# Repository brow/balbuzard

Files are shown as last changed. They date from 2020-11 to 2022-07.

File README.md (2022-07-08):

# Balbuzard

Balbuzard is a compact, ergonomic keyboard with 34–38 keys.

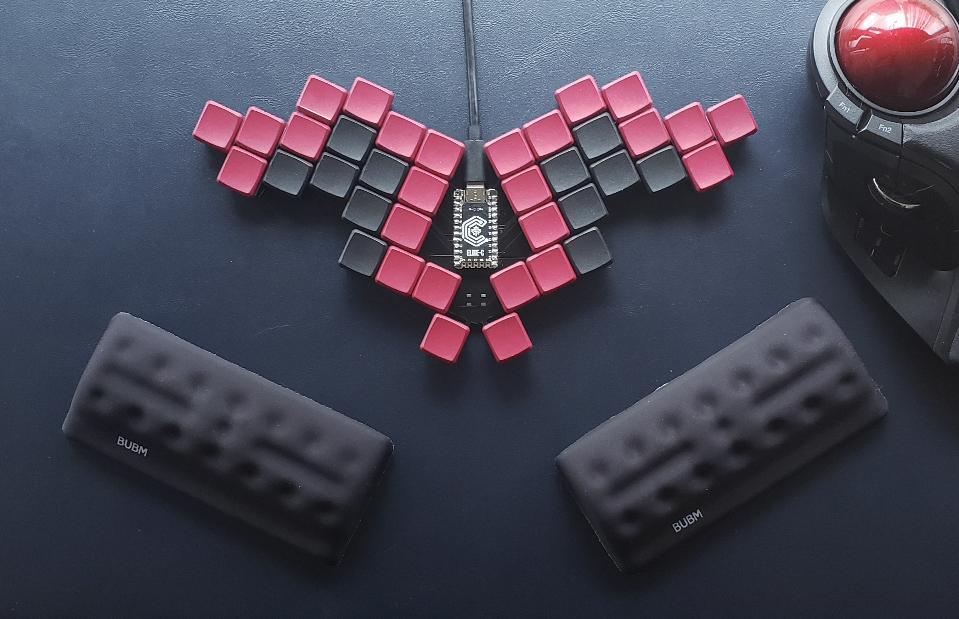
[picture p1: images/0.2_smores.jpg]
assembled Balbuzard 0.2


_Balbuzard 0.2 by [@smores56](https://github.com/smores56)_

## How do you type on that?
I've used Balbuzard as my main keyboard since 2019. My keymap looks like this:

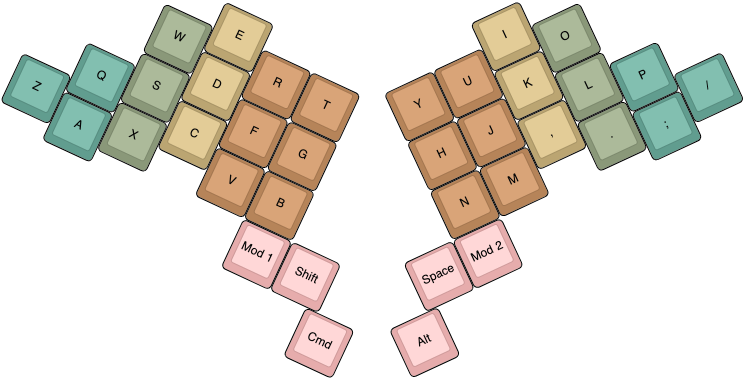
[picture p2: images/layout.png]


_Mod 1_ and _Mod 2_ activate alternate layers of the keymap, which contain symbols, arrows, backspace, etc.

## Versions

### [0.2: Low-profile](https://github.com/brow/balbuzard/releases/tag/v0.2)

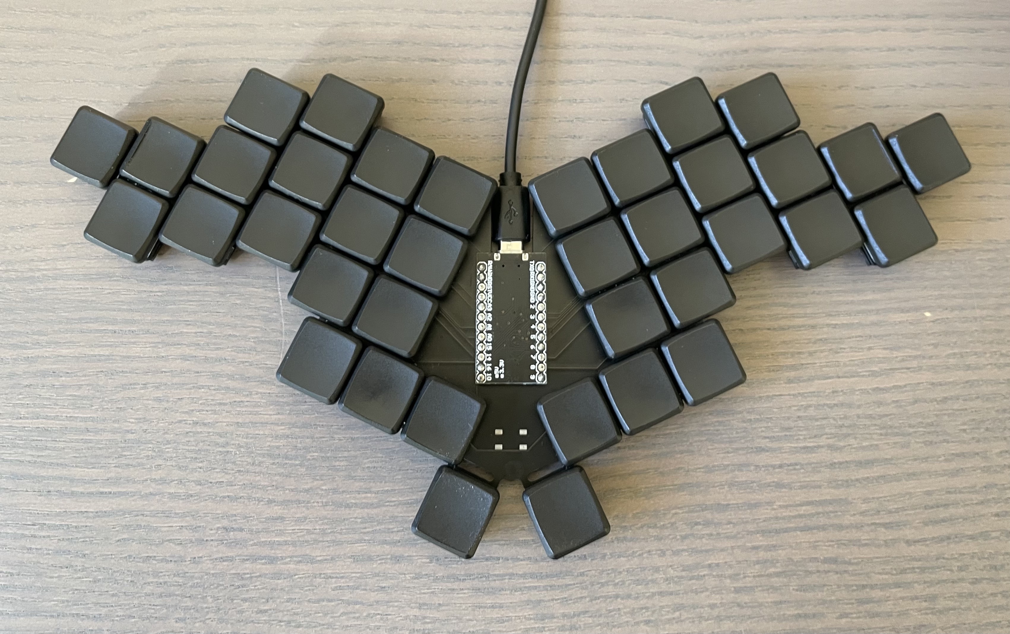
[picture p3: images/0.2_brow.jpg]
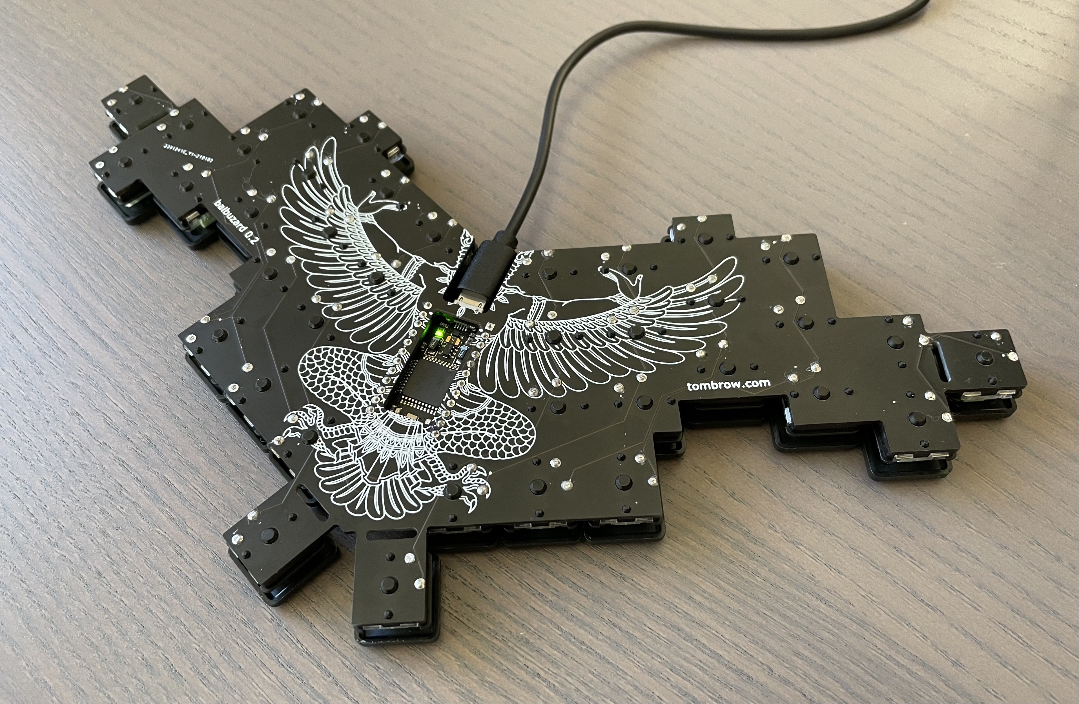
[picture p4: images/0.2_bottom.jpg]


- 34–38 keys
- Compatible with Choc (low-profile) switches
- SMD diodes concealed within switches
- Silkscreen on bottom
- Tighter key spacing
- Viewing window under microcontroller
- Adjustments to positions of columns and thumb keys
- **Firmware:** [brow/qmk_firmware@balbuzard-0.2](https://github.com/brow/qmk_firmware/tree/balbuzard-0.2)

### [0.1: Classic](https://github.com/brow/balbuzard/releases/tag/v0.1)

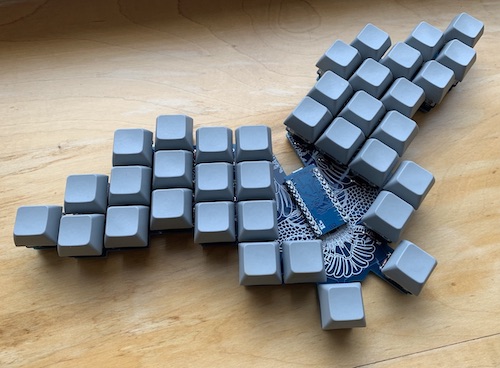
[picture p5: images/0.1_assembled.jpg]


- 36 keys
- Compatible with MX, Alps, and Choc (low-profile) switches
- Through-hole diodes nestled between switches
- Silkscreen on top
- **Firmware:** [brow/qmk_firmware@balbuzard-0.1](https://github.com/brow/qmk_firmware/tree/balbuzard-0.1)

## Using this repository

This repo contains the [Ergogen](https://github.com/mrzealot/ergogen) configuration that generates the KiCad PCB file.

Assuming you have [npm installed](https://www.npmjs.com/get-npm):

``` sh
git clone --recursive git@github.com:brow/balbuzard.git
cd balbuzard
make
```

Find the generated PCB at `output/pcbs/main.kicad_pcb`.

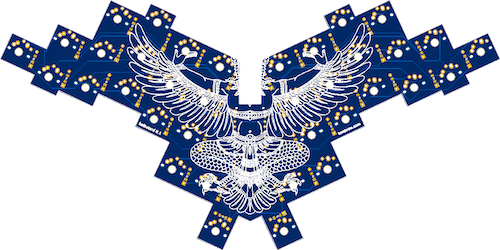
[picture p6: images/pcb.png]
pcb thumbnail image


## More photos

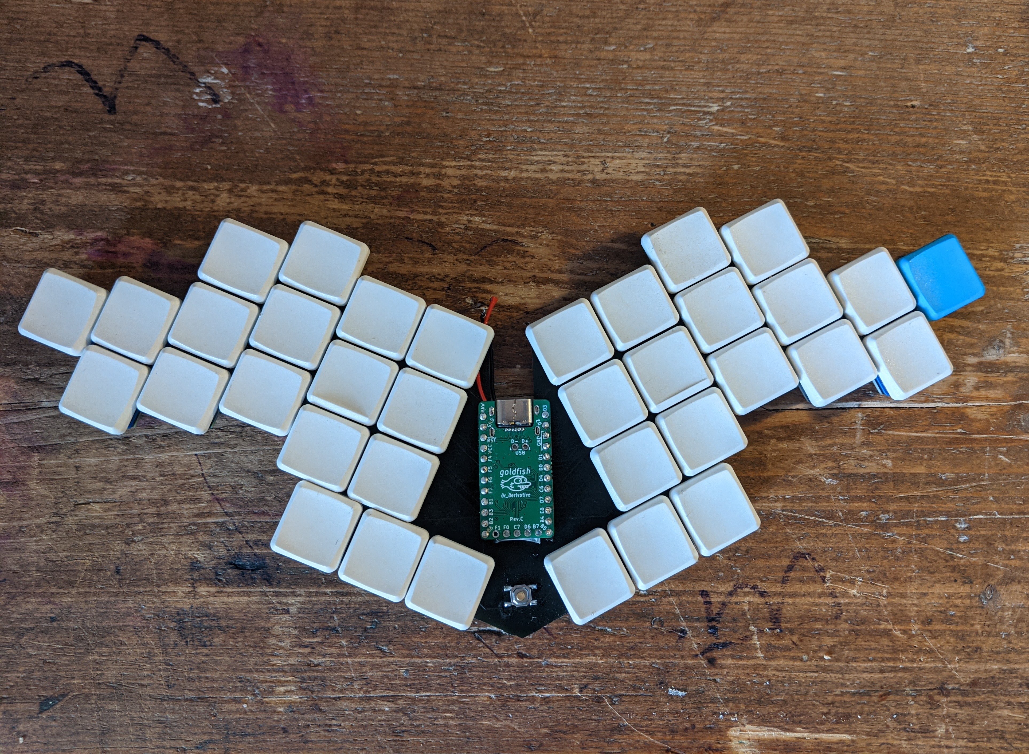
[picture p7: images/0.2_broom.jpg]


_Balbuzard 0.2 with optional thumbs removed, by [@davidphilipbarr](https://github.com/davidphilipbarr)_

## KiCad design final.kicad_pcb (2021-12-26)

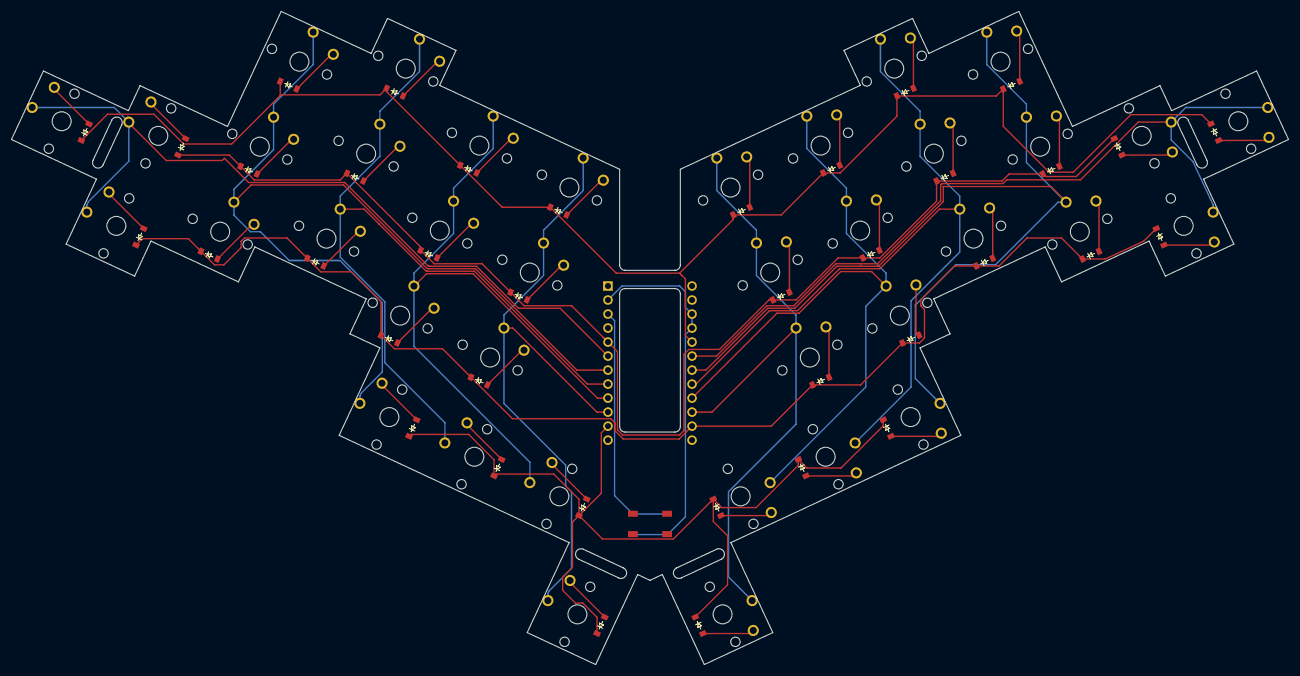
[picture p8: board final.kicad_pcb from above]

Board: 2 copper layers, 231.5 x 118.4 mm, 77 parts (0 on the bottom side), 52 nets.

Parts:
B1: SW_TACT_ALPS_SKQGABE010
D1, D2, D3, D4, D5, D6, D7, D8, D9, D10, D11, D12, D13, D14, D15, D16, D17, D18, D19, D20, D21, D22, D23, D24, D25, D26, D27, D28, D29, D30, D31, D32, D33, D34, D35, D36, D37, D38: ComboDiode
S1, S2, S3, S4, S5, S6, S7, S8, S9, S10, S11, S12, S13, S14, S15, S16, S17, S18, S19, S20, S21, S22, S23, S24, S25, S26, S27, S28, S29, S30, S31, S32, S33, S34, S35, S36, S37, S38: PG1350

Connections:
P2: D3.1, D6.1, D9.1, D12.1, D15.1, D22.1, D25.1, D28.1, D31.1, D34.1
P3: S20.2, S21.2, S22.2
P4: S23.2, S24.2, S25.2, S35.2
P5: S26.2, S27.2, S28.2, S36.2
P6: S29.2, S30.2, S31.2, S37.2
P7: S32.2, S33.2, S34.2, S38.2
P8: D1.1, D4.1, D7.1, D10.1, D13.1, D20.1, D23.1, D26.1, D29.1, D32.1
P14: S13.2, S14.2, S15.2, S19.2
P15: S10.2, S11.2, S12.2, S18.2
P16: D16.1, D17.1, D18.1, D19.1, D35.1, D36.1, D37.1, D38.1
P18: S7.2, S8.2, S9.2, S17.2
P19: S4.2, S5.2, S6.2, S16.2
P20: S1.2, S2.2, S3.2
P21: D2.1, D5.1, D8.1, D11.1, D14.1, D21.1, D24.1, D27.1, D30.1, D33.1
far_thumb: D19.2, S19.1
home_thumb: D18.2, S18.1
index_bottom: D10.2, S10.1
index_home: D11.2, S11.1
index_top: D12.2, S12.1
inner_bottom: D13.2, S13.1
inner_home: D14.2, S14.1
inner_top: D15.2, S15.1
middle_bottom: D7.2, S7.1
middle_home: D8.2, S8.1
middle_top: D9.2, S9.1
mirror_far_thumb: D38.2, S38.1
mirror_home_thumb: D37.2, S37.1
mirror_index_bottom: D29.2, S29.1
mirror_index_home: D30.2, S30.1
mirror_index_top: D31.2, S31.1
mirror_inner_bottom: D32.2, S32.1
mirror_inner_home: D33.2, S33.1
mirror_inner_top: D34.2, S34.1
mirror_middle_bottom: D26.2, S26.1
mirror_middle_home: D27.2, S27.1
mirror_middle_top: D28.2, S28.1
mirror_near_thumb: D36.2, S36.1
mirror_nearer_thumb: D35.2, S35.1
mirror_pinky_bottom: D20.2, S20.1
mirror_pinky_home: D21.2, S21.1
mirror_pinky_top: D22.2, S22.1
mirror_ring_bottom: D23.2, S23.1
mirror_ring_home: D24.2, S24.1
mirror_ring_top: D25.2, S25.1
near_thumb: D17.2, S17.1
nearer_thumb: D16.2, S16.1
pinky_bottom: D1.2, S1.1
pinky_home: D2.2, S2.1
pinky_top: D3.2, S3.1
ring_bottom: D4.2, S4.1
ring_home: D5.2, S5.1
ring_top: D6.2, S6.1

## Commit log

2021-12-26 remove MX & Alps footprints
2021-12-26 tighten switch size to 13.7 mm
2021-12-26 new default diode placement
2021-12-26 simulate LED hole diode position
2021-12-26 position diode in center of LED hole
2021-12-26 reset switch
2021-12-26 update silkscreen
2021-12-26 remove backside silks
    [final.kicad_pcb]
